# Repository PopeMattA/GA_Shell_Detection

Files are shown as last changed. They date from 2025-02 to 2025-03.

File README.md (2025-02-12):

# General Atomics Shell Detection


## 📌 Overview
This Arduino project controls a **servo motor, a DC motor, a relay, and a sensor system**. It integrates a **PCA9685 servo driver**, **push buttons**, and a **sensor** for detection. The system:
- Moves a **servo motor** between two positions (0° and 180°) via **button inputs**.
- **Toggles a relay** every 5 seconds.
- Controls a **DC motor** using PWM signals.
- **Detects an object** using a sensor and triggers a response.
- Outputs **debugging information** via Serial Monitor.

---

## ⚙️ Hardware Components
| Component | Description |
|---|---|
| **Arduino Uno/Mega/Nano**  | Main microcontroller |
| **PCA9685** | 16-channel PWM driver for servos |
| **Servo Motor** | Rotates between predefined angles |
| **DC Motor** | Controlled via PWM signals |
| **Relay Module** | Toggles ON/OFF every 5 seconds |
| **Keyence Fiber Optic Sensor** | Detects objects and sends TTL signals |
| **Push Buttons (2x)** | Controls the servo position |
| **Wires & Power Supply** | Connects components and provides power |

---

## 🔌 Wiring Diagram
| Arduino Pin  | Component |
|---|---|
| `SDA/SCL` | **PCA9685 (I2C)** |
| `9` | **Servo Motor PWM** |
| `10` | **DC Motor PWM** (via H-Bridge) |
| `4` | **Relay Control** |
| `2` | **Sensor Digital Input** |
| `12, 13` | **Push Buttons (Good Sump / Bad Sump)** |
| `5, 6, 7` | **DC Motor Control (ENA, IN1, IN2)** |

---

## 🔧 Installation & Setup

### 1️⃣ Install Dependencies
1. Install **Arduino IDE**: [Download Here](https://www.arduino.cc/en/software)
2. Install **Adafruit PWM Servo Driver Library**:
   - Open **Arduino IDE** → Go to **Library Manager** (`Sketch` > `Include Library` > `Manage Libraries`).
   - Search for **Adafruit PWMServoDriver** and install it.

### 2️⃣ Upload Code to Arduino
1. Open `Arduino IDE`
2. Copy and paste the provided code into the editor.
3. Connect your Arduino board and select the correct **Board & Port**.
4. Click **Upload** to flash the program.

---

## ▶️ Usage Instructions
- The system **resets the servo** when powered on.
- **Press the buttons**:
  - `Good Sump (Pin 12)` → Moves servo to `0°`
  - `Bad Sump (Pin 13)` → Moves servo to `180°`
- The **relay toggles every 5 seconds**.
- The **DC motor runs continuously**.
- The **sensor detects objects**, triggering `"Shell detected! Take a picture!"` in the Serial Monitor.

## 📞 Contact
📩 Author: Matthew Pope
🔗 GitHub: PopeMattA
📧 Email: [popematt1204@gmail.com]

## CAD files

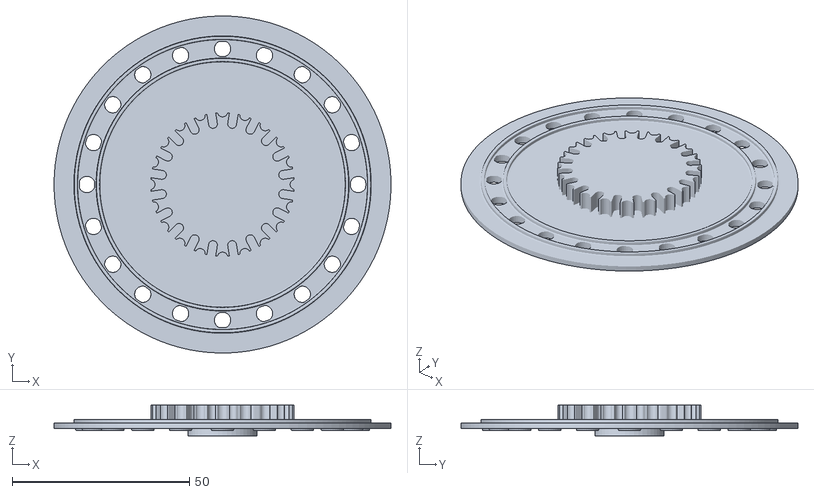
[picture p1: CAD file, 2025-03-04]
CAD_FILES/GA_CAD/3_4mmChamberv5 v4.stl
95.0 x 95.0 x 8.60

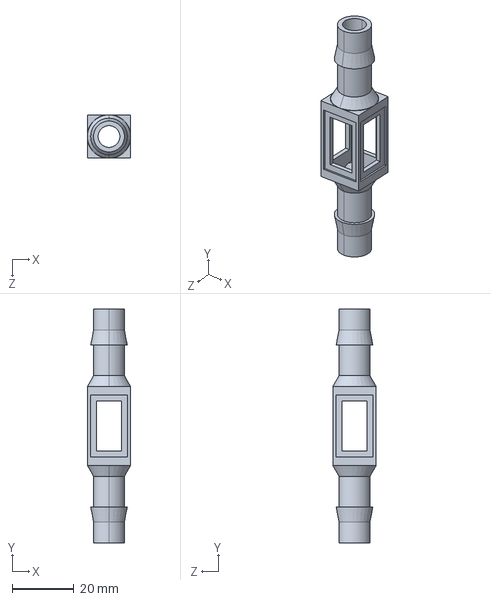
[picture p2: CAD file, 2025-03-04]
CAD_FILES/GA_CAD/Inspection Chamber Housing V4.STEP
14.0 x 75.5 x 14.0 mm

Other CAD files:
CAD_FILES/GA_CAD/3_4mmHopperv4 v3.f3d
CAD_FILES/GA_CAD/3_4mmPlatformv5 v5.f3d
CAD_FILES/GA_CAD/DC_Motor v3.f3d
CAD_FILES/GA_CAD/Holder_thing v13.f3d
CAD_FILES/GA_CAD/Motor_Holder v1.f3d
CAD_FILES/GA_CAD/New_Gear_Assembly v14.f3z
CAD_FILES/GA_CAD/Platform Lid.f3d
CAD_FILES/GA_CAD/tube holder_side v1.f3d

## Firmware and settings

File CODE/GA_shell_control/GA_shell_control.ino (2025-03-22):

#include <Wire.h>
#include <Adafruit_PWMServoDriver.h>

#define RELAY_PIN 4
#define FLOAT_SWITCH_PIN 8  // Pin connected to the float switch
#define FLOAT_SWITCH_PIN_2 9 // Pin connected to second float switch
#define SENSOR_PIN 2        // NPN sensor connected to digital pin 2
#define CAMERA_PIN 11       // LED/camera trigger on pin 13

// Create PWM servo driver instance
Adafruit_PWMServoDriver pwm = Adafruit_PWMServoDriver();

// Define constants for servo positions
const int SERVOMIN = 150;  
const int SERVOMAX = 600; 

const int servoChannel = 0;  // The servo connected to channel 0 on PCA9865
const int position0 = 450;   // 0 degrees
const int position180 = SERVOMAX; // 180 degrees

// Define button commands
const int goodSumpButton = 12;  // Button to move servo to 0°
const int badSumpButton = 13;   // Button to move servo to 180°

bool motor_running = false;
bool servo_reset_done = false;
int currentPositionState = 0; 

bool relayState = false;
unsigned long lastRelayToggleTime = 0;

int ena = 5;
int in1 = 6;
int in2 = 7;

// Physical parameters - adjust these to your actual setup
const float shellDiameter = 4;         
const float sensorWidth = 2.5;          
const float distanceToCamera = 200.0;   
const float tubeDiameterAtSensor = 7.0;  
const float tubeDiameterAtCamera = 10;  
const float expansionPoint = 100;      
const float DELAY_CONSTANT = 50; // Time Delay Constant for LED (camera)

// Timing variables
volatile unsigned long detectionStartTime = 0;
volatile unsigned long detectionEndTime = 0;
volatile bool shellDetected = false;
volatile bool measurementComplete = false;
volatile float shellVelocity = 0.0;
volatile float adjustedVelocity = 0.0;
volatile float triggerDelay = 0; 

// Non-blocking timing
unsigned long triggerTime = 0;
unsigned long cameraOffTime = 0;
bool triggerScheduled = false;
bool cameraOn = false;

void setup() {
    Serial.begin(9600);
    Serial.println("System Initialized");

    // Initialize PCA9685 for servo
    pwm.begin();
    pwm.setPWMFreq(50);

    pinMode(goodSumpButton, INPUT_PULLUP);
    pinMode(badSumpButton, INPUT_PULLUP);

    pinMode(ena, OUTPUT);
    pinMode(in1, OUTPUT);
    pinMode(in2, OUTPUT);

    pinMode(FLOAT_SWITCH_PIN, INPUT_PULLUP);
    pinMode(FLOAT_SWITCH_PIN_2, INPUT_PULLUP);
    pinMode(RELAY_PIN, OUTPUT);
    digitalWrite(RELAY_PIN, HIGH);  

    pinMode(SENSOR_PIN, INPUT_PULLUP);
    pinMode(CAMERA_PIN, OUTPUT);
    digitalWrite(CAMERA_PIN, LOW);

    attachInterrupt(digitalPinToInterrupt(SENSOR_PIN), sensorChange, CHANGE);
}

void loop() {
    reset_servo();
    //handleButtonsTime();
    handleButtonsManual();
    toggleRelay();
    runDC();
    sensorDetect();
    handleCameraTrigger();
}

void reset_servo() {
    if (!servo_reset_done) {
        setServoPosition(600);
        delay(1000);
        setServoPosition(150);
        delay(1500);
        setServoPosition(600);
        delay(1000);

        servo_reset_done = true;
        Serial.println("Servo is reset and ready.");
    }
}

void handleButtonsTime() {
    static bool lastGoodSumpState = LOW;
    static bool lastBadSumpState = LOW;
    static unsigned long goodSumpPressedTime = 0;
    static unsigned long badSumpPressedTime = 0;
    static bool goodSumpPending = false;
    static bool badSumpPending = false;
    static float delayTime = 3000;  // Default to 3 seconds if no sensor data

    bool goodSumpState = digitalRead(goodSumpButton);
    bool badSumpState = digitalRead(badSumpButton);
    unsigned long currentMillis = millis();

    // Calculate delay time dynamically based on shell speed
    if (shellVelocity > 0) {
        float switchingDistance = 50.0;  // Distance to switching point (adjust as needed)
        delayTime = (switchingDistance / shellVelocity) * 1000.0;  // Convert to milliseconds
    }

    // Detect button press and start countdown
    if (goodSumpState == HIGH && lastGoodSumpState == LOW) {
        Serial.println("Good sump button pressed, waiting dynamically...");
        goodSumpPressedTime = currentMillis;
        goodSumpPending = true;
    }

    if (badSumpState == HIGH && lastBadSumpState == LOW) {
        Serial.println("Bad sump button pressed, waiting dynamically...");
        badSumpPressedTime = currentMillis;
        badSumpPending = true;
    }

    // Check if calculated time has passed and move servo accordingly
    if (goodSumpPending && (currentMillis - goodSumpPressedTime >= delayTime)) {
        Serial.println("Moving to good sump.");
        setServoPosition(position0);
        currentPositionState = 0;
        goodSumpPending = false; // Reset flag
    }

    if (badSumpPending && (currentMillis - badSumpPressedTime >= delayTime)) {
        Serial.println("Moving to bad sump.");
        setServoPosition(position180);
        currentPositionState = 180;
        badSumpPending = false; // Reset flag
    }

    lastGoodSumpState = goodSumpState;
    lastBadSumpState = badSumpState;
}

void handleButtonsManual() {
    static bool lastGoodSumpState = LOW;
    static bool lastBadSumpState = LOW;

    bool goodSumpState = digitalRead(goodSumpButton);
    bool badSumpState = digitalRead(badSumpButton);

    if (goodSumpState == HIGH && lastGoodSumpState == LOW) {
        Serial.println("Moving to good sump.");
        setServoPosition(position0);
        currentPositionState = 0;
    }

    if (badSumpState == HIGH && lastBadSumpState == LOW) {
        Serial.println("Moving to bad sump.");
        setServoPosition(position180);
        currentPositionState = 180;
    }

    lastGoodSumpState = goodSumpState;
    lastBadSumpState = badSumpState;
}

void toggleRelay() {
    int floatState = digitalRead(FLOAT_SWITCH_PIN);
    int floatState2 = digitalRead(FLOAT_SWITCH_PIN_2);
    if (floatState == LOW || floatState2 == LOW) {  
        digitalWrite(RELAY_PIN, HIGH);  
        //Serial.println("Flow no go");
    } else {
        digitalWrite(RELAY_PIN, LOW);  
        //Serial.println("Flow go");
    }
}

void runDC() {
    digitalWrite(in1, HIGH);
    digitalWrite(in2, LOW);
    analogWrite(ena, 24);
}

void setServoPosition(int position) {
    pwm.setPWM(servoChannel, 0, position);
}

void sensorDetect() {
    if (measurementComplete) {

        sensorChange();
        float shellPassTime = (detectionEndTime - detectionStartTime) / 1000.0;  

        Serial.print("Shell detected! Pass time: ");
        Serial.print(shellPassTime, 2);
        Serial.println(" ms");

        Serial.print("Initial velocity: ");
        Serial.print(shellVelocity);
        Serial.println(" m/s");

        adjustedVelocity = shellVelocity * sq(tubeDiameterAtSensor / tubeDiameterAtCamera);

        Serial.print("Adjusted velocity after tube expansion: ");
        Serial.print(adjustedVelocity);
        Serial.println(" m/s");

        if (expansionPoint < distanceToCamera) {
            float timeToExpansion = expansionPoint / shellVelocity / 1000.0;
            float timeAfterExpansion = (distanceToCamera - expansionPoint) / adjustedVelocity / 1000.0;
            triggerDelay = (timeToExpansion + timeAfterExpansion) * 1000.0;
        } else {
            triggerDelay = ((distanceToCamera + DELAY_CONSTANT) / shellVelocity) * 1000.0;
        }

        Serial.print("Trigger delay: ");
        Serial.print(triggerDelay);
        Serial.println(" ms");

        triggerTime = millis() + triggerDelay;
        triggerScheduled = true;

        measurementComplete = false;
    }
}

void handleCameraTrigger() {
    if (triggerScheduled && millis() >= triggerTime) {
        digitalWrite(CAMERA_PIN, HIGH);
        Serial.println("Camera triggered!");
        cameraOffTime = millis() + 50;  
        cameraOn = true;
        triggerScheduled = false;
    }

    if (cameraOn && millis() >= cameraOffTime) {
        digitalWrite(CAMERA_PIN, LOW);
        cameraOn = false;
    }
}

// Interrupt handler for sensor state changes
void sensorChange() {
    if (digitalRead(SENSOR_PIN) == LOW) {
        detectionStartTime = micros();
        shellDetected = true;
    } else if (shellDetected) {
        detectionEndTime = micros();
        shellDetected = false;

        float timeDiff = (detectionEndTime - detectionStartTime) / 1000000.0;
        float effectiveWidth = shellDiameter + sensorWidth;

        shellVelocity = effectiveWidth / timeDiff / 1000.0;
        measurementComplete = true;
    }
}

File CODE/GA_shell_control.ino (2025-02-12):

#include <Wire.h>
#include <Adafruit_PWMServoDriver.h>
#define RELAY_PIN 4

// Create PWM servo driver instance
Adafruit_PWMServoDriver pwm = Adafruit_PWMServoDriver();

// Define constants for servo positions
const int SERVOMIN = 150;  // 150 should be the actual min or maybe 0
// Minimum pulse length (0°)
const int SERVOMAX = 600; // Maximum pulse length (180°)

// Define servo channel and positions
const int servoChannel = 0;  // The servo connected to channel 0 on PCA9865
const int position0 = 300;  // 0 degrees
const int position180 = SERVOMAX; // 180 degrees

const int motorPin1 = 9;
const int motorPin2 = 10;
const int motorPWM = 11;

//Define button commands
const int goodSumpButton = 12;  // Button to move servo to 0°
const int badSumpButton = 13;   // Button to move servo to 180°

const int sensorPin = 2;

//const int BUTTON_PIN = 7; // pin of button on Arduino
bool motor_running = false;
bool servo_reset_done = false;

int currentPositionState = 0; // Tracks current state (0 or 180 degrees)

bool relayState = false;
unsigned long lastRelayToggleTime = 0;
const unsigned long relayInterval = 5000; // 5 seconds

int ena = 5;
int in1 = 6;
int in2 = 7;

void setup() {
  Serial.begin(9600); // Initialize Serial communication
  Serial.println("Press 'g' to go to position 0 degrees (Good sump).");
  Serial.println("Press 'b' to go to position 180 degrees (Bad sump).");

  // Initialize the PCA9685
  pwm.begin();
  pwm.setPWMFreq(50); // Set frequency to 50 Hz for servos

  pinMode(goodSumpButton, INPUT_PULLUP);
  pinMode(badSumpButton, INPUT_PULLUP);
  pinMode(RELAY_PIN, OUTPUT);

  pinMode(ena, OUTPUT);
  pinMode(in1, OUTPUT);
  pinMode(in2, OUTPUT);

  pinMode(sensorPin, INPUT_PULLUP);  // This enables the internal pull-up resistor
}

void loop() {
  reset_servo();
  handleButtons();
  toggleRelay();
  runDC();
  sensorDetect();
}

void reset_servo() {
  if (!servo_reset_done) {
    setServoPosition(600);
    delay(1000);

    setServoPosition(150);
    delay(1500);

    setServoPosition(600);
    delay(1000);

    servo_reset_done = true;
    Serial.println("Servo is reset and you can now dump.");
  }
}

void handleButtons() {
  if (digitalRead(goodSumpButton) == LOW) {
    if (currentPositionState != 0) {
      Serial.println("Moving to good sump.");
      setServoPosition(position0);
      currentPositionState = 0;
    } else {
      Serial.println("Already at good sump.");
    }
  }

  if (digitalRead(badSumpButton) == LOW) {
    if (currentPositionState != 180) {
      Serial.println("Moving to bad sump.");
      setServoPosition(position180);
      currentPositionState = 180;
    } else {
      Serial.println("Already at bad sump.");
    }
  }
}

void toggleRelay() {
  unsigned long currentMillis = millis();

  if (currentMillis - lastRelayToggleTime >= relayInterval) {
    relayState = !relayState;  // Toggle relay state
    digitalWrite(RELAY_PIN, relayState ? HIGH : LOW);
    lastRelayToggleTime = currentMillis;  // Reset timer

  }
}

void runDC() {
  digitalWrite(in1, HIGH);
  digitalWrite(in2, LOW);
  analogWrite(ena, 24);
}

// Function to set servo position
void setServoPosition(int position) {
  pwm.setPWM(servoChannel, 0, position); // Set PWM signal for the servo
}

void sensorDetect() {
  if (digitalRead(sensorPin) == LOW) {
    Serial.println("Shell detected! Take a picture!");
  }
}

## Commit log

2025-02-13 adding relay separate timing
2025-02-18 adding float switch
2025-02-25 change to relay for float switch and to servo buttons
2025-03-04 adding CAD files
    [3_4mmChamberv5 v4.stl, 3_4mmHopperv4 v3.f3d, 3_4mmPlatformv5 v5.f3d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]
2025-03-09 new float switch
2025-03-10 add delay for camera
2025-03-14 adding final assembly
